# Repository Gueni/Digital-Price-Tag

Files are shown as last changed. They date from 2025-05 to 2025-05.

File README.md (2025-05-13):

# 📦 Digital Price Tag – ANNA-B112 + E-Ink + CR Battery

A low-power, wireless **digital price tag** using:

- **ANNA-B112-01B** Bluetooth LE module  
- **E-Ink Display** (e.g., 2.13” GDEH0213B72)
- **CR2032 Battery**
- Designed for **supermarket shelf labeling**, with OTA updates via BLE

---
<p align="center">
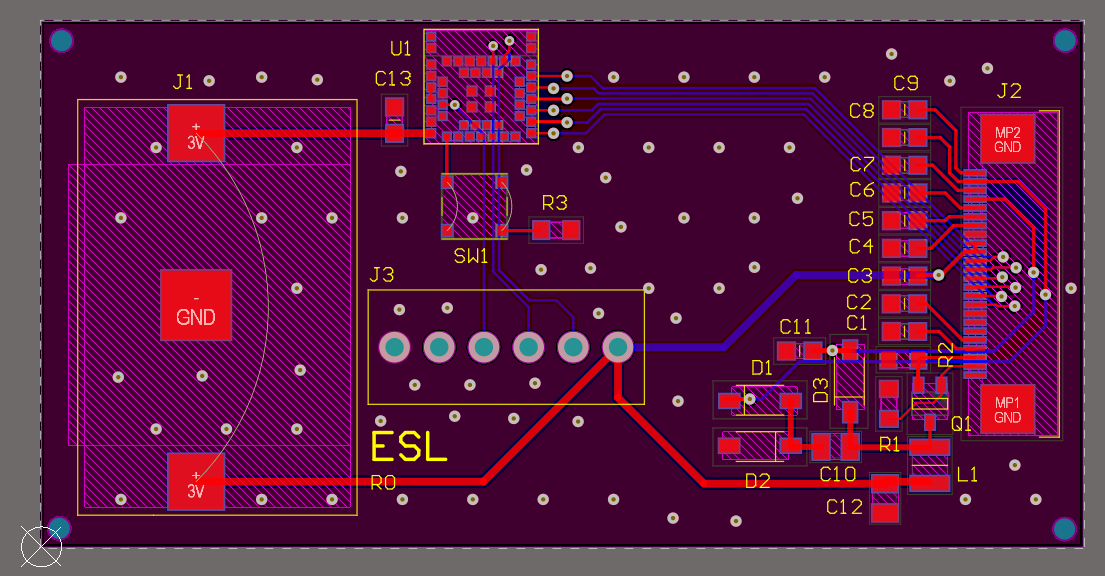
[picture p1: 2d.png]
  
</p>

<p align="center">
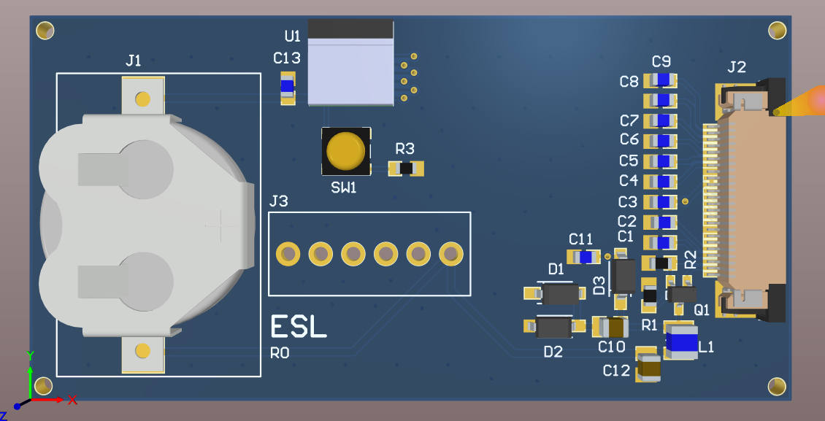
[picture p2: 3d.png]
  
</p>

## 📘 Features

- BLE-enabled wireless updates via central device (app/gateway)
- Ultra-low-power mode suitable for coin cell operation
- Bistable E-Ink display – no power needed to retain the image
- Custom GATT service for remote pricing updates
- Sleep current < 2 µA (target)
- Display refreshes triggered by BLE or timer

---

## 📦 Hardware Components

| Component | Description |
|---|---|
| ANNA-B112-01B | BLE module (nRF52832) |
| E-Ink Display | 2.13” SPI EPD (GDEH0213B72 or similar) |
| CR2032 Battery | 3V coin cell |
| LDO Regulator | 3.3V LDO for stable display voltage |
| Level shifter | Optional, for voltage compatibility  |
| Passive components | Pull-ups, caps, resistors |

---

## 🧠 Firmware Architecture

- **Nordic SDK** or **nRF Connect SDK (Zephyr RTOS)**
- **BLE Custom GATT Service**
  - `UUID 0x180C` – Price Tag Service
  - Characteristics:
    - `UUID 0x2A56` – Text/Price (UTF-8 string)
    - `UUID 0x2A57` – Display Refresh Trigger
- E-Ink driver via SPI (Waveshare compatible)
- Deep Sleep using `sd_power_system_off()` until BLE wake or RTC interrupt

---

## 🔧 Setup Instructions

1. **Hardware Wiring**
   - Connect E-Ink SPI lines (CLK, MOSI, CS, DC, RST, BUSY) to ANNA-B112
   - Power via CR2032 with 3.3V LDO regulator
   - Add pull-ups for I2C (if used), and decoupling capacitors

2. **Build and Flash**
   - Clone project and configure for your SDK
   - Compile using SEGGER Embedded Studio or `west` (if using Zephyr)
   - Flash via SWD or set up BLE DFU for OTA firmware upgrades

3. **BLE Test**
   - Install **nRF Connect** mobile app
   - Scan, connect, and write pricing string to `0x2A56`
   - Write any value to `0x2A57` to trigger refresh

---

## 📉 Power Considerations

| Mode | Power Consumption |
|---|---|
| Sleep (RTC) | ~1.5 µA |
| BLE Advertising | ~10–20 µA average |
| Display Refresh | ~15–20 mA (spike) |

- Target average: **<10 µA** with infrequent updates
- Battery Life Estimate: **~1 year** on CR2032

---

## 📁 Directory Structure

```
project/
├── src/
│   ├── main.c
│   ├── ble_price_service.c
│   └── eink_driver.c
├── include/
│   └── eink_driver.h
├── sdk_config.h
├── Makefile / CMakeLists.txt
└── README.md
```

---

## 📡 OTA and Gateway

Optional BLE gateway (e.g., ESP32, Raspberry Pi) can:

- Push price updates over BLE
- Schedule updates via MQTT / HTTP
- Manage multiple shelf labels in bulk

---

## 🔄 Future Enhancements

- NFC tap-to-update fallback
- QR code on E-Ink
- Temp/humidity sensors for smart shelves
- Battery voltage and signal strength reporting

---

## 📚 References

- [ANNA-B112 Datasheet](https://www.u-blox.com/en/product/anna-b1-series)
- [Nordic nRF52 SDK](https://www.nordicsemi.com/Products/Development-software/nRF5-SDK)
- [Waveshare E-Ink Displays](https://www.waveshare.com/wiki/Main_Page)
- [BLE GATT Specifications](https://www.bluetooth.com/specifications/gatt/)

---

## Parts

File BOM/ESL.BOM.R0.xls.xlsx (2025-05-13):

Designator | Quantity | DES | FTP | MAN | MANREF | NOTE | SUP | SUPREF | TOL | Value 1 | Value 2
C1, C2, C3, C4, C5, C6, C7, C8, C9, C11, C13 | 11 | Multilayer Ceramic Capacitors MLCC - SMD/SMT 1uF 50V X5R +/-10% 0603 Gen Purp | 0603 | Taiyo Yuden | UMK107BJ105KA-T | _ | Mouser | 963-UMK107BJ105KA-T | 10% | 1uF | 50V
C10, C12 | 2 | Multilayer Ceramic Capacitors MLCC - SMD/SMT | 0805 | Murata Electronics | GRM21BZ71H475KE15K | _ | Mouser | 81-GRM21BZ71H475KE5K | 10% | 4.7uF | 50V
D1, D2, D3 | 3 | Schottky Diodes & Rectifiers 0.5A 30V | SOD-123 | ON Semiconductor | MBR0530T1G | _ | Mouser | 863-MBR0530T1G | _ | 500 mA | 30 V
J1 | 1 | Coin Cell Battery Holders 3012 matte Tin Coin Coin Cell Retainer | SMD/SMT | Keystone Electronics | 3092 | _ | Mouser | 534-3092 | _ | _ | 16 mm
J2 | 1 | FFC & FPC Connectors WR-FPC 0.5mm SMT ZIF 24Pin Hrztl Top Cont | SMD/SMT | Wurth Elektronik | 68712414022 | _ | Mouser | 710-68712414022 | _ | 24pts | _
J3 | 1 | 282834-6 - Bornier fil-à-carte, 2.54 mm, 6 Voies, 30 AWG, 16 AWG, 1.4 mm², Par vis | THT | BUCHANAN - TE CONNECTIVITY | 282834-6 | _ | Farnell | 2396255 | _ | 6pts | 2.54mm
L1 | 1 | Fixed Inductors 10.0uH 460mOhms1.0A +/-20% 2.5x2.0x1.2mm | 2520 | Murata Electronics | 1239AS-H-100M=P2 | _ | Mouser | 81-1239AS-H-100MP2 | 20 % | 10 uH | 1 A
Q1 | 1 | MOSFET 30V Vds 12V Vgs SC70-3 | SOT-323-3 | Vishay Semiconductors | SI1308EDL-T1-GE3 | _ | Mouser | 78-SI1308EDL-T1-GE3 | _ | 1.5 A | 30 V
R1, R3 | 2 | YAGEO (PHYCOMP) RC0603FR-0710KL RESISTANCE COUCHE EPAISSE 10K 0.1W 1% | 0603 | YAGEO | RC0603FR-0710KL | _ | Farnell | 9238603 | 1% | 10K | 0.1W
R2 | 1 | CRL0603-FW-R470ELF - Résistance à puce CMS, Couche épaisse, 0603 [1608 Metric], 0.47 ohm, Série CRL, Couche épaisse | 0603 | BOURNS | CRL0603-FW-R470ELF | _ | Farnell | 2328098 | 1% | 0.47R | 0.1W
SW1 | 1 | Tactile Switches 50mA 12VDC .25mm H 160gf SPST 3.7x3.7mm | _ | E-Switch | TL3312NF160Q | _ | Mouser | 612-TL3312NF160Q | _ | _ | _
U1 | 1 | Bluetooth Bluetooth v5.0 Transceiver Module 2.4GHz Integrated, Chip Surface Mount | _ | U-Blox | ANNA-B112-01B | _ | Digi-Key | 672-ANNA-B112-01BTR-ND | _ | _ | _

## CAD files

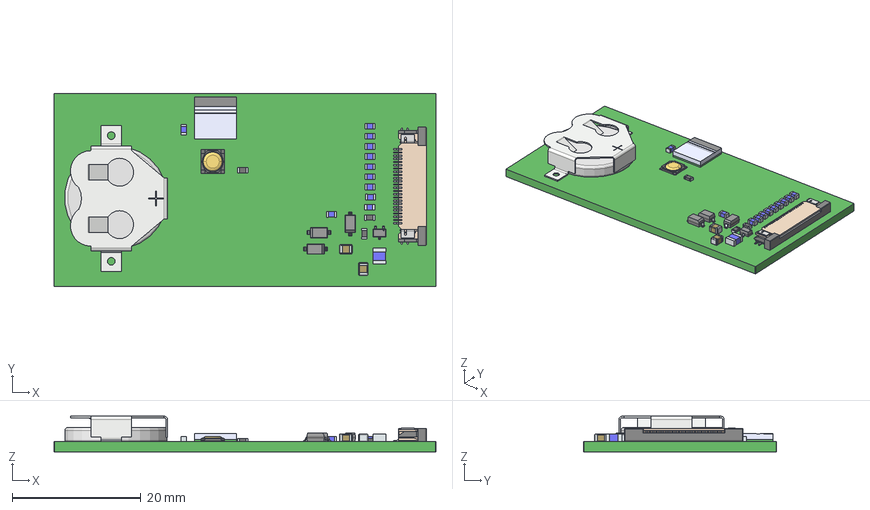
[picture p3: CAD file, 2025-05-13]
ExportSTEP/[No Variations].step
59.4 x 30.0 x 5.55 mm
User Library-001085 cr-1632 batt
keystone-PN3092
term1 x 15
term2 x 15
ANNA-B112--3DModel-STEP-56544
PinsArrayL
FilletPinR x 4
6871xx14022_PIN x 24
6871xx14022_Patte
6871xx14022_Patte_2
68712414022_CAP
FilletPinL x 3

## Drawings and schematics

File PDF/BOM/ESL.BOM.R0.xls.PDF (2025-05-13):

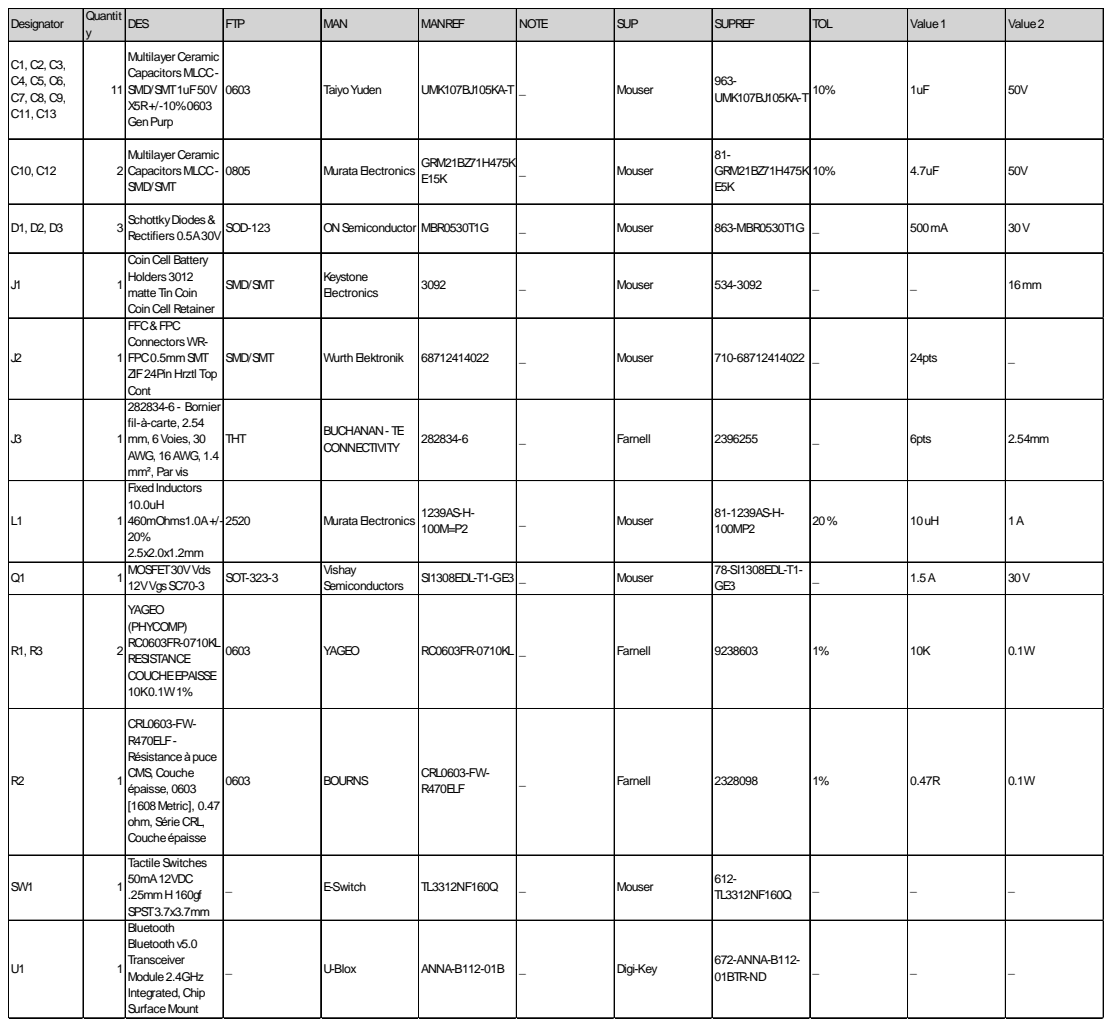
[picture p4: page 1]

Designator | Quantit y | DES | FTP | MAN | MANREF | NOTE | SUP | SUPREF | TOL | Value1 | Value2

C1, C2, C3, C4, C5, C6, C7, C8, C9, C11, C13 | 11 | Multilayer Ceramic Capacitors MLCC-SMD/SMT1uF50V X5R+/-10%0603 GenPurp | 0603 | TaiyoYuden | UMK107BJ105KA-T | _ | Mouser | 963-UMK107BJ105KA-T 10% | | 1uF | 50V

C10, C12 | 2 | Multilayer Ceramic Capacitors MLCC-SMD/SMT | 0805 | MurataElectronics | GRM21BZ71H475K E15K | _ | Mouser | 81-GRM21BZ71H475K E5K | 10% | 4.7uF | 50V

D1, D2, D3 | 3 | SchottkyDiodes& Rectifiers 0.5A30V | SOD-123 | ONSemiconductor | MBR0530T1G | _ | Mouser | 863-MBR0530T1G | _ | 500mA | 30V

J1 | 1 | CoinCell Battery Holders 3012 matteTinCoin CoinCell Retainer | SMD/SMT | Keystone Electronics | 3092 | _ | Mouser | 534-3092 | _ | _ | 16mm

J2 | 1 | FFC&FPC ConnectorsWR-FPC0.5mmSMT ZIF24PinHrztl Top Cont | SMD/SMT | WurthElektronik | 68712414022 | _ | Mouser | 710-68712414022 | _ | 24pts | _

J3 | 1 | 282834-6- Bornier fil-à-carte, 2.54 mm, 6Voies, 30 AWG, 16AWG, 1.4 mm², Par vis | THT | BUCHANAN- TE CONNECTIVITY | 282834-6 | _ | Farnell | 2396255 | _ | 6pts | 2.54mm

L1 | 1 | FixedInductors 10.0uH 460mOhms1.0A+/-20% 2.5x2.0x1.2mm | 2520 | MurataElectronics | 1239AS-H-100M=P2 | _ | Mouser | 81-1239AS-H-100MP2 | 20% | 10uH | 1A

Q1 | 1 | MOSFET30VVds 12VVgsSC70-3 | SOT-323-3 | Vishay Semiconductors | SI1308EDL-T1-GE3 | _ | Mouser | 78-SI1308EDL-T1-GE3 | _ | 1.5A | 30V

R1, R3 | 2 | YAGEO (PHYCOMP) RC0603FR-0710KL RESISTANCE COUCHEEPAISSE 10K0.1W1% | 0603 | YAGEO | RC0603FR-0710KL | _ | Farnell | 9238603 | 1% | 10K | 0.1W

R2 | 1 | CRL0603-FW-R470ELF-Résistanceàpuce CMS, Couche épaisse, 0603 [1608Metric], 0.47 ohm, Série CRL, Coucheépaisse | 0603 | BOURNS | CRL0603-FW-R470ELF | _ | Farnell | 2328098 | 1% | 0.47R | 0.1W

SW1 | 1 | TactileSwitches 50mA12VDC .25mmH160gf SPST3.7x3.7mm | _ | E-Switch | TL3312NF160Q | _ | Mouser | 612-TL3312NF160Q | _ | _ | _

U1 | 1 | Bluetooth Bluetoothv5.0 Transceiver Module2.4GHz Integrated, Chip SurfaceMount | _ | U-Blox | ANNA-B112-01B | _ | Digi-Key | 672-ANNA-B112-01BTR-ND | _ | _ | _

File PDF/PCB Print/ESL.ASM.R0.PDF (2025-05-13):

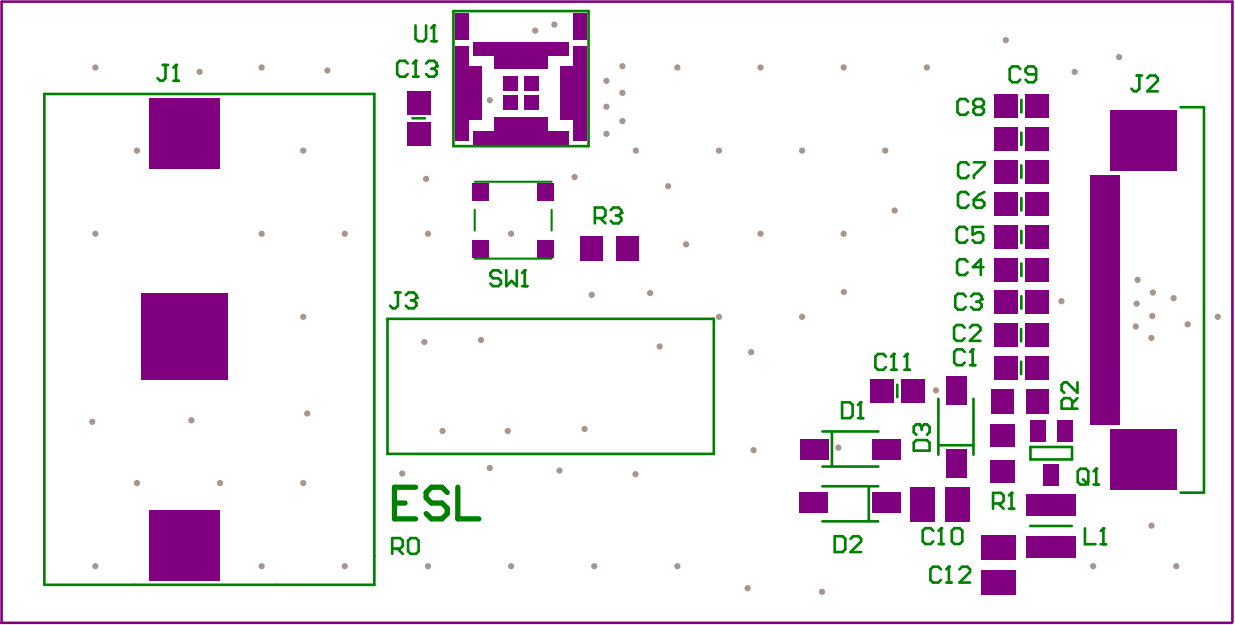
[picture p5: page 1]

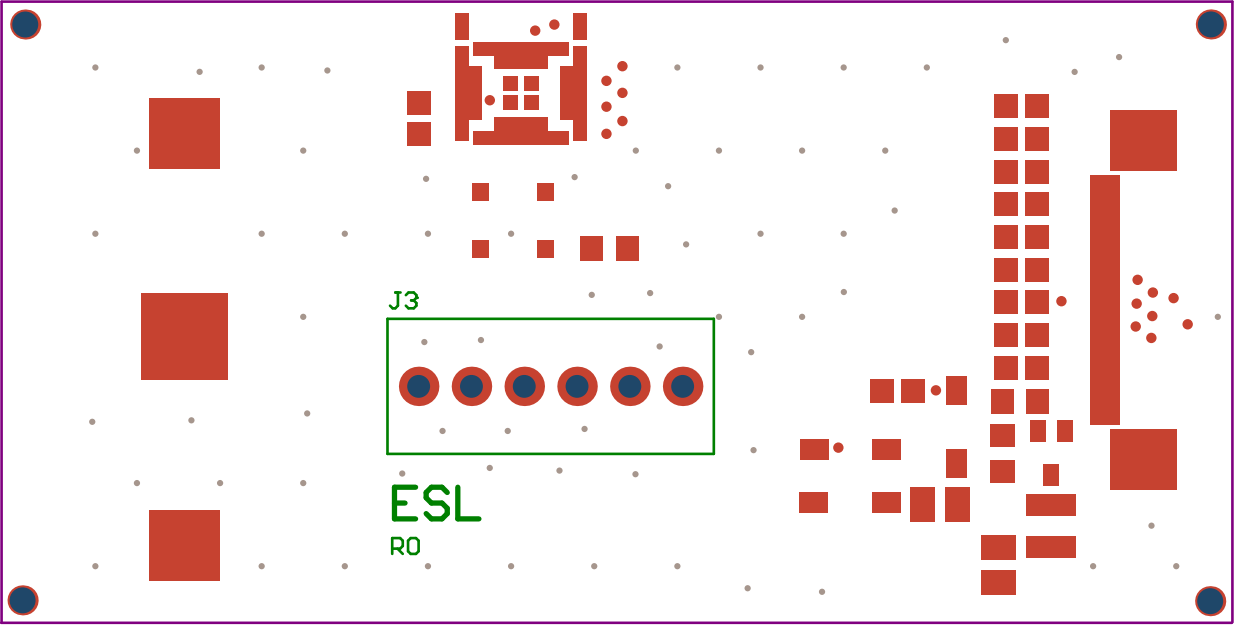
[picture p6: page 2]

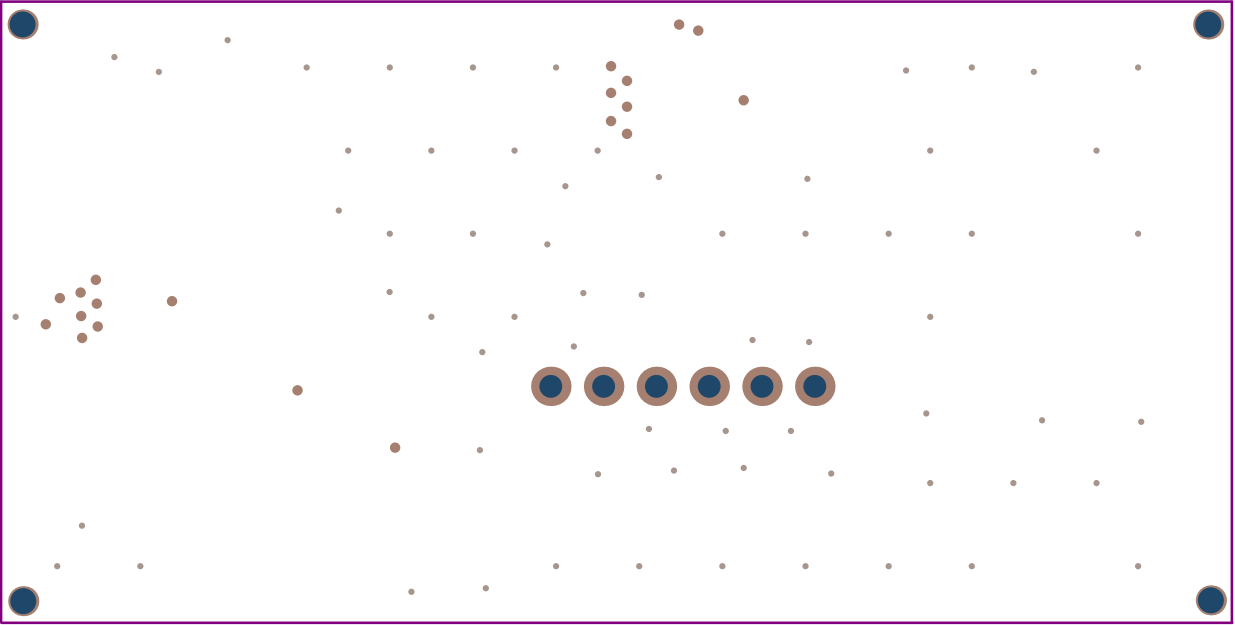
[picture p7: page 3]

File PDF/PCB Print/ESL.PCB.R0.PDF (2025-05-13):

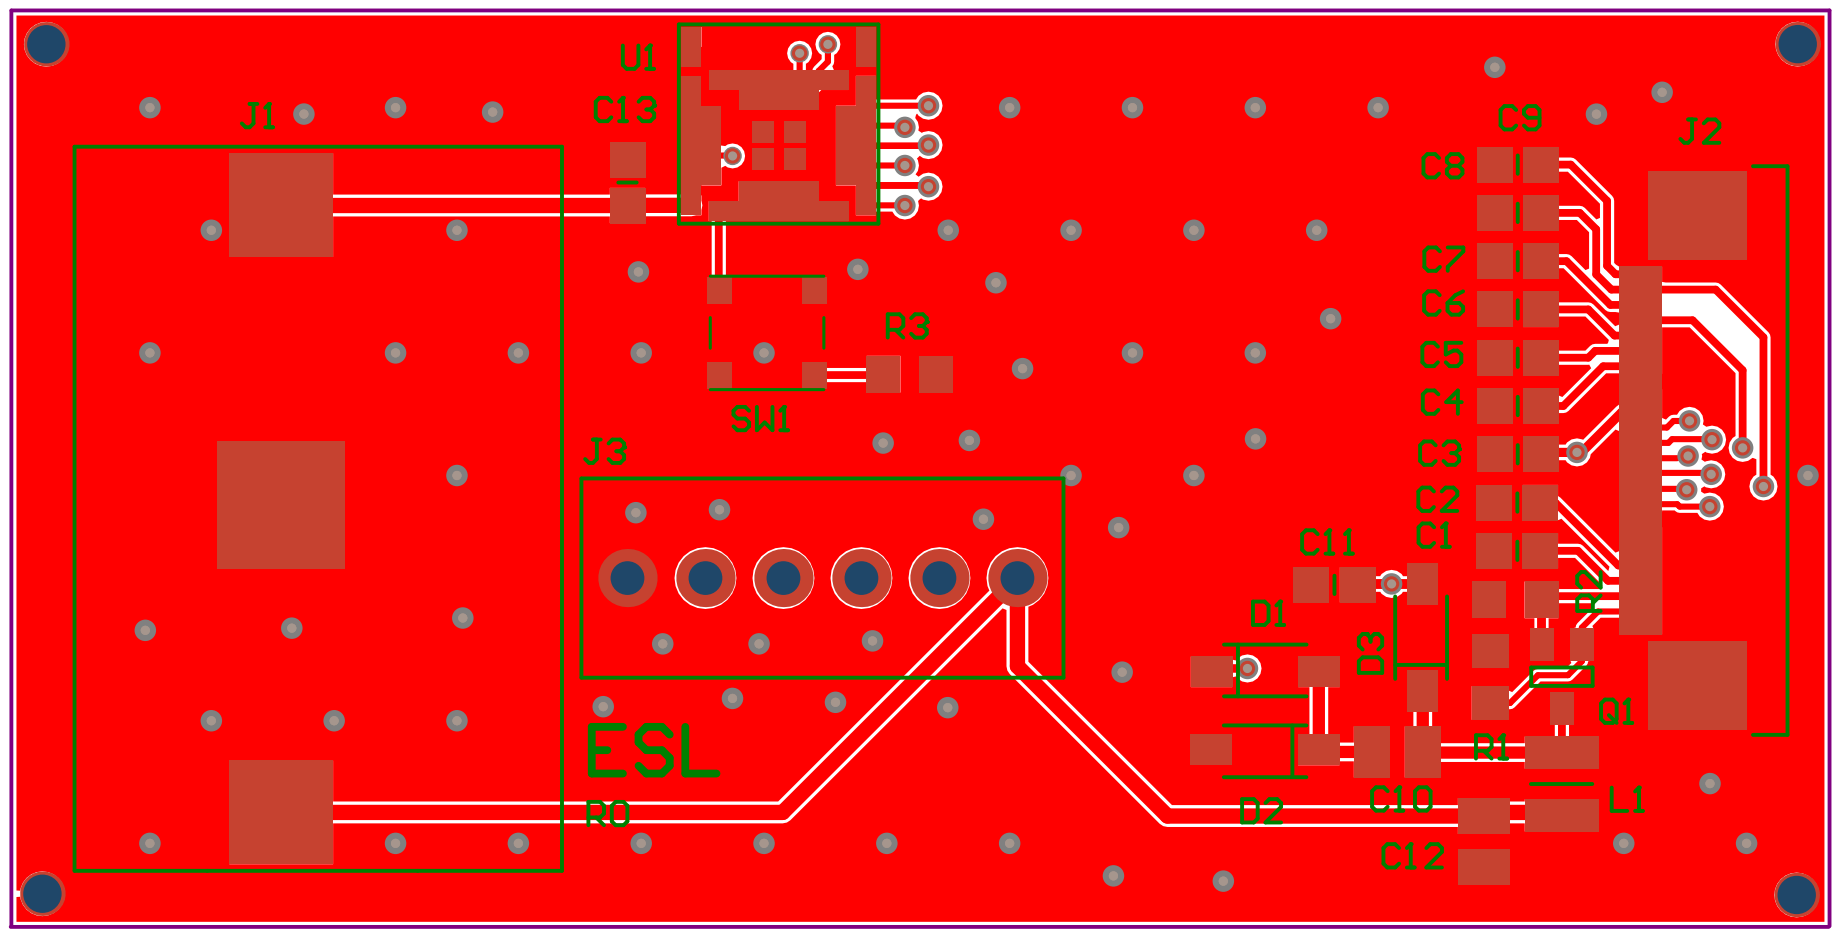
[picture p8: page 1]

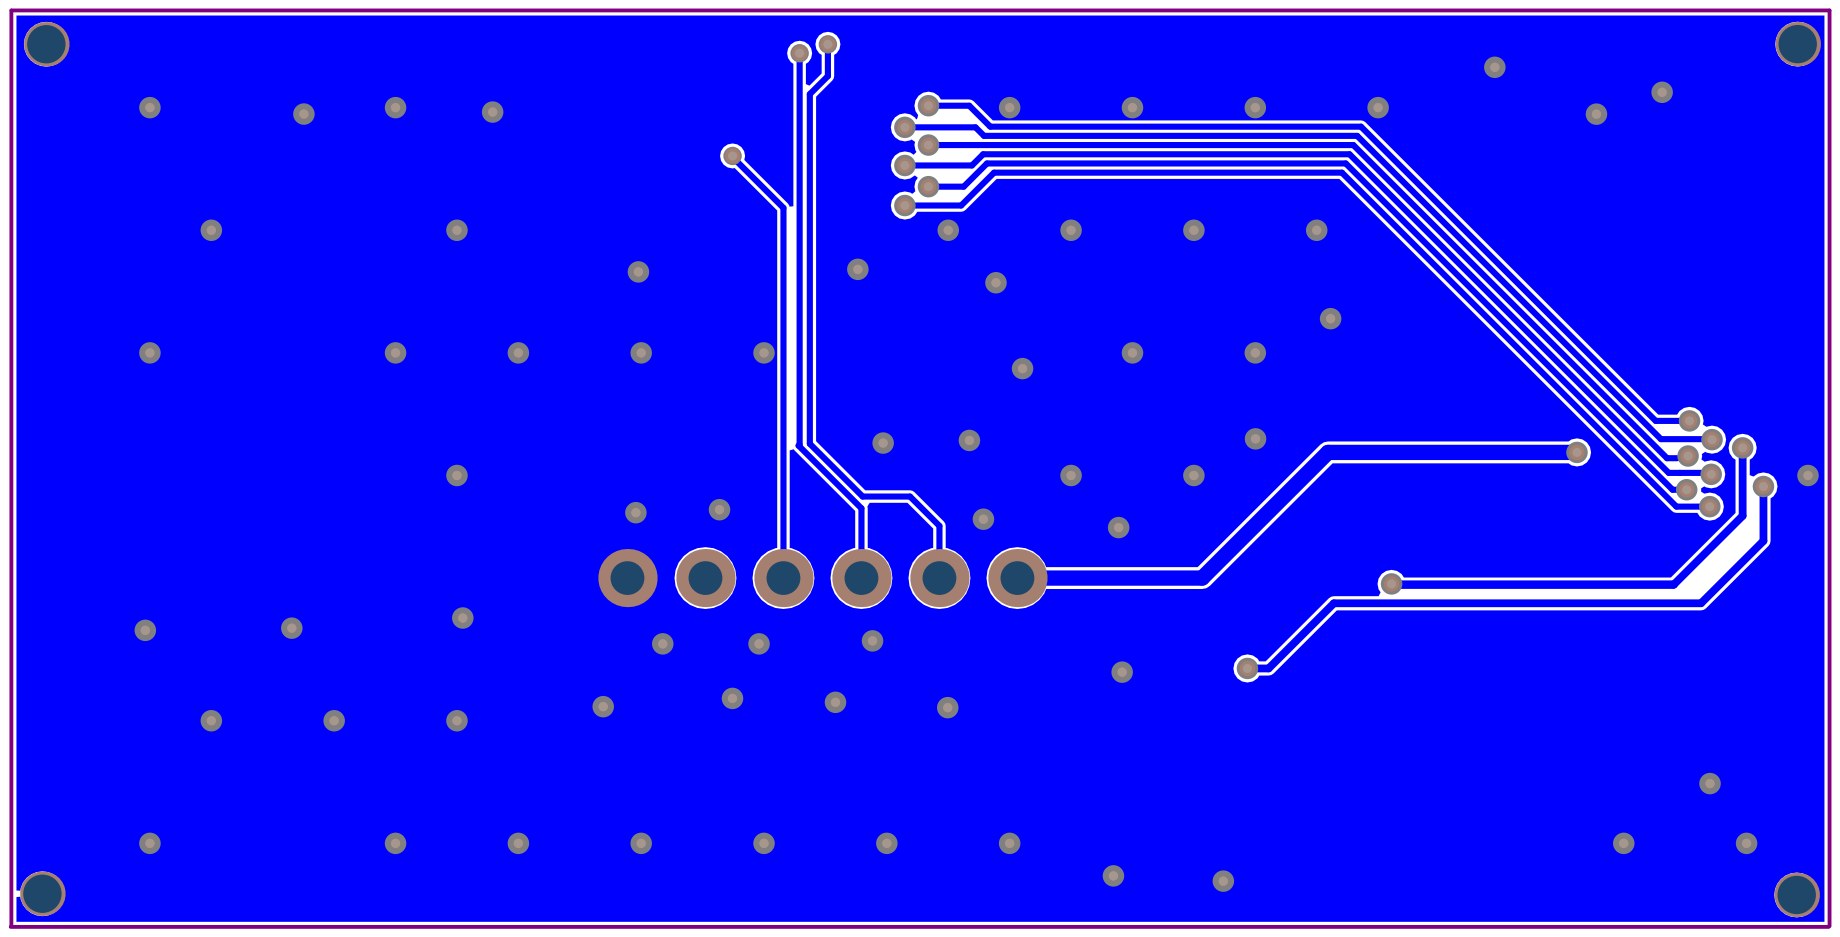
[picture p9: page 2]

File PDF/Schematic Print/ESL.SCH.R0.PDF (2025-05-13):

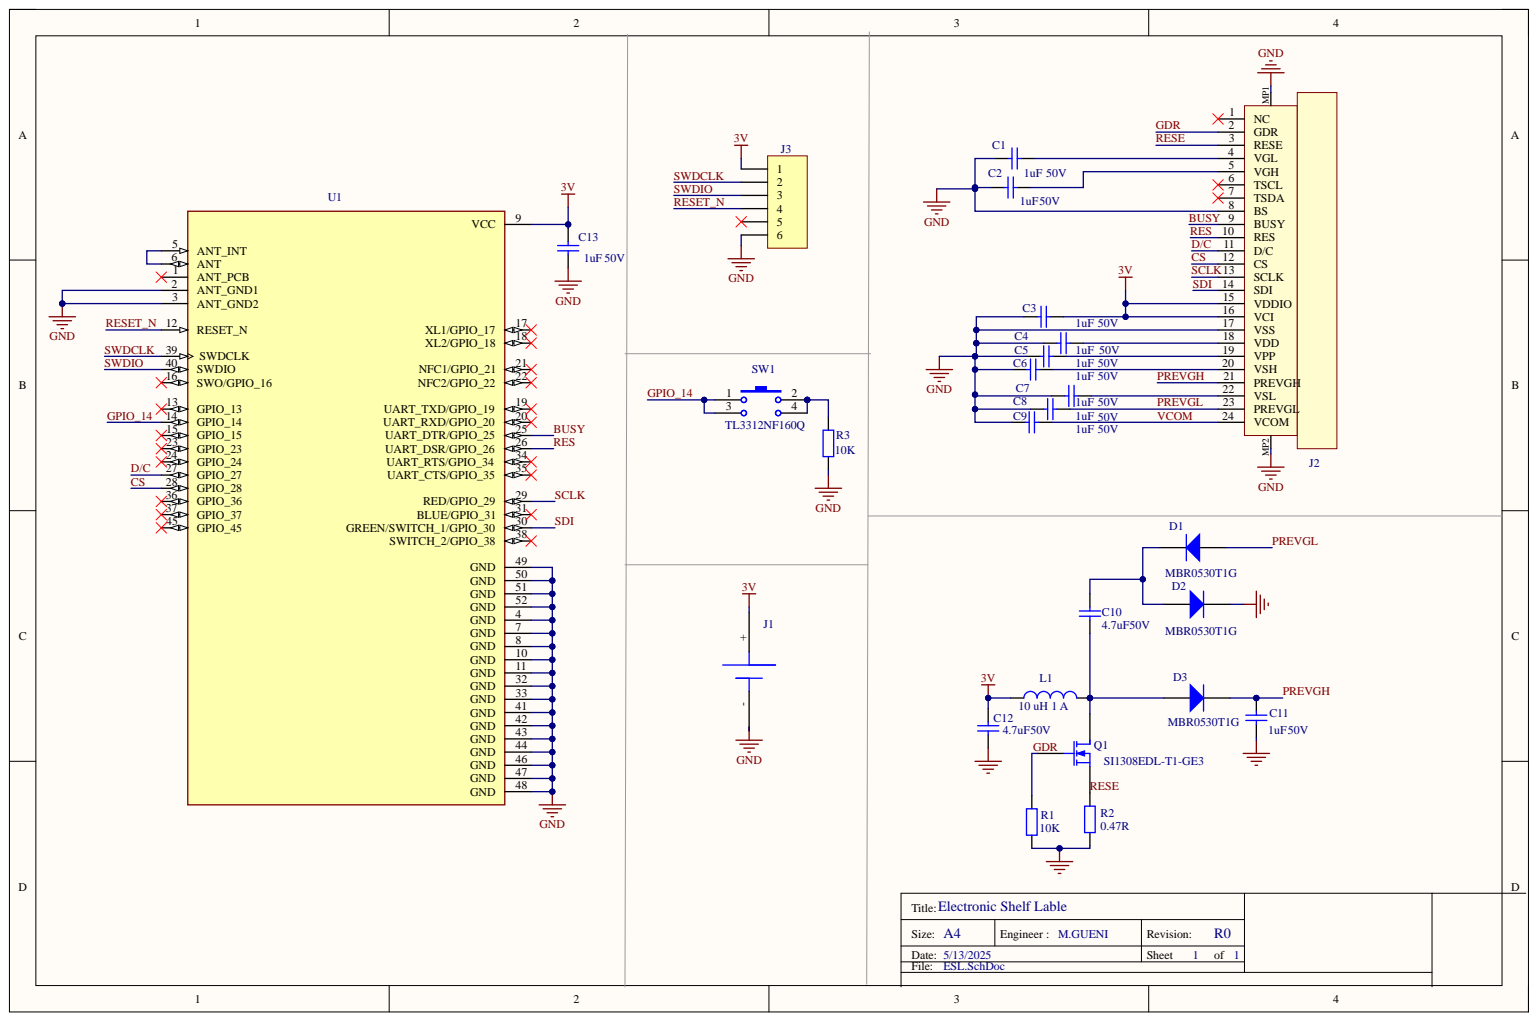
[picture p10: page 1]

Title: Electronic Shelf Lable

Size: A4 | Engineer : M.GUENI | Revision: R0

Date: 5/13/2025 | | Sheet 1 of 1

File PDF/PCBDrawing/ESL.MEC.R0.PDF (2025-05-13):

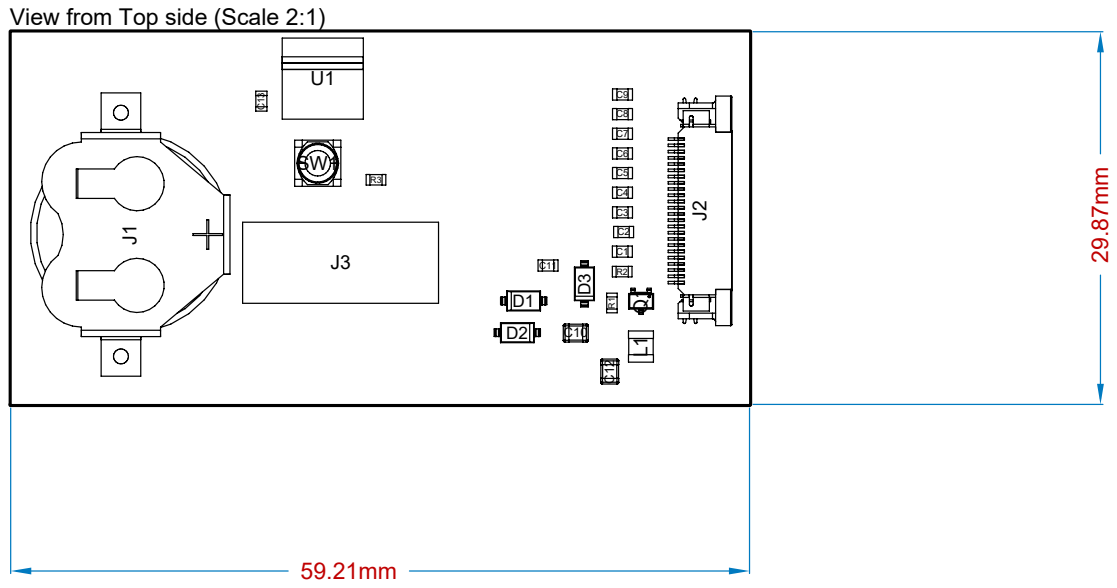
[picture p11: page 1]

View from Top side (Scale 2:1)




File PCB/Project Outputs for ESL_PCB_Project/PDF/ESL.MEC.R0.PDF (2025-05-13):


View from Top side (Scale 2:1)

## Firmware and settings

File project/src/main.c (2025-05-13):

#include "nrf.h"
#include "ble_price_service.h"
#include "eink_driver.h"
#include "nrf_pwr_mgmt.h"

int main(void) {
    // Init BLE
    ble_stack_init();
    gap_params_init();
    gatt_init();
    advertising_init();
    services_init();
    conn_params_init();

    // Init E-Ink
    eink_init();
    eink_clear();
    eink_print("READY");

    advertising_start();
    nrf_pwr_mgmt_init();

    while (1) {
        idle_state_handle();
    }
}

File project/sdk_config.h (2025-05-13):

#ifndef SDK_CONFIG_H
#define SDK_CONFIG_H

#define NRF_SDH_ENABLED 1
#define NRF_SDH_BLE_ENABLED 1
#define NRF_SDH_BLE_VS_UUID_COUNT 1
#define NRF_SDH_BLE_GAP_DATA_LENGTH 27
#define NRF_SDH_BLE_PERIPHERAL_LINK_COUNT 1
#define NRF_SDH_BLE_TOTAL_LINK_COUNT 1

#define BLE_ADVERTISING_ENABLED 1
#define BLE_ADVERTISING_ADV_INTERVAL 64

#define BLE_GATTS_ENABLED 1
#define BLE_GATTS_ATTR_TAB_SIZE 1408

#define APP_TIMER_ENABLED 1
#define APP_TIMER_CONFIG_RTC_FREQUENCY 0
#define APP_TIMER_CONFIG_IRQ_PRIORITY 6

#define NRFX_SPI_ENABLED 1
#define NRFX_SPI0_ENABLED 1
#define SPI_ENABLED 1
#define SPI0_ENABLED 1
#define SPI_DEFAULT_CONFIG_FREQUENCY 0x02000000
#define SPI_DEFAULT_CONFIG_MODE 0
#define SPI_DEFAULT_CONFIG_BIT_ORDER 0
#define SPI_DEFAULT_CONFIG_IRQ_PRIORITY 6

#define NRF_LOG_ENABLED 1
#define NRF_LOG_BACKEND_UART_ENABLED 1
#define NRF_LOG_DEFAULT_LEVEL 3

#define NRF_PWR_MGMT_ENABLED 1
#define NRF_FSTORAGE_ENABLED 1
#define FDS_ENABLED 1

#define RETARGET_ENABLED 1

#endif // SDK_CONFIG_H

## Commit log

2025-05-13 Add project outputs generation report for ESL export process
    - Created a new report detailing the output generation for the ESL.R0 file.
    - Included timestamps for the start and finish of the output generation.
    - Documented the type of output, source document, and generated file information.
    [ESL.BOM.R0.xls.xlsx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]
2025-05-13 Add README.md for Digital Price Tag project with detailed features, setup instructions, and power considerations
